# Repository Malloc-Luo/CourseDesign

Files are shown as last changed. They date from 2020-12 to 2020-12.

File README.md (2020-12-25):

## 简单温控系统

[Malloc-Luo/CourseDesign: 大三上微机原理课程设计 (github.com)](https://github.com/Malloc-Luo/CourseDesign)

### 一，创新

*   显示设定值和当前值—数码管
*   键盘设定温度
*   遥控控制温度
*   自制遥控器

### 二，技术层面

*   A/D转换
*   串口通信及传输协议设置
*   定时器中断
*   温度控制算法
*   ~~PID算法温度控制~~

### 三，设想

*   **设定温度**：键盘输入法；遥控法
*   **温度显示**：一个显示当前值，一个显示设定值，指示灯指示
*   **读取温度**：A/D转换
*   ~~**风扇与加热设备控制**：PID算法~~

### 四，任务分配

| 任务 | 人员 |
| --- | --- |
| 课程设计报告 | 马昊，常英剑 |
| 答辩PPT | 刘梦泽，李昱棋 |
| 遥控模块软件设计 | 刘梦泽，李昱棋 |
| 温控模块按键+数码管显示软件 | 马昊 |
| 温控模块AD转换温度获取 | 杨博然，常英剑，李昱棋 |
| 温控算法 | 李昱棋 |
| 通信协议设计及实现 | 李昱棋 |
| 电路原理图设计/绘制 | 李昱棋 |
| 遥控模块电路焊接 | 刘梦泽，杨博然 |

### 五，材料

[物品清单](https://docs.qq.com/sheet/DU2lkakxWcFdqTlZT?tab=BB08J2)

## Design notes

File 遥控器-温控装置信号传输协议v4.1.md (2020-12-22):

## 遥控器-温控装置信号传输协议v4.1

### 一、下位机与上位机串口通信协议：

上位机遥控器端蓝牙串口做为`master`，下位机蓝牙串口做`slaver`。串口参数：

*   波特率：9600
*   停止位：1
*   校验方式：无校验
*   帧长度：8 bit

每一帧数据有4 byte，分为 起始帧，指令帧，数据帧。

| Byte | Note |
| :--: | :---: |
|  1 | 0xA5 Frame Header |
|  2 | 指令帧 |
|  3 | 数据帧高8位 |
|  4 | 数据帧低8位 |

#### 数据位：

数据位为`%3.1f`类型的浮点数乘以10之后强制转换成`uint16_t`的数据，大小为0~999

#### 控制位：

控制位指示数据位的类型，占4bit

| Value | Note |
| --- | --- |
| 0x01  `SET_VAL` | 数据位为温度设定值 |
| 0x02  `ACTUL_VAL` | 数据位为温度当前值 |
| 0x04  ` RESET` | 重置温度最低值 |
| `Value` \| 0xf0 | 强制同步模式 |

#### 强制同步模式：

为了避免数据发生冲突而加入强制同步模式，下位机蓝牙模块由离线转为在线模式后的2400ms内为强制同步模式，此时下位机发送控制位的搞四位为`0xf`，在强制同步模式下：

*   温控模块、遥控模块的按键不可用
*   温控模块的不在串口中断中改变设定值、参考值、实际值
*   遥控模块解析指令时需要将接收到的指令按位与`0x0f`

### 二、程序实现示例：

合成发送数据帧：

```c
float tempf;
int16_t tempi= (int16_t)(tempf * 10);
uint8_t construction;

void bt_send_data(uint8_t *cmd, int16_t *dat)
{
    uint8_t * ptr = (uint8_t *)dat;
    /* 数据帧头0xa5 */
    uart_send(FRAME_HEADER);
    /* 指令帧 */
    uart_send(*cmd);
    /* 数据帧 */
    uart_send(*(ptr + 0));
    uart_send(*(ptr + 1));
}
```

还原接收数据帧：

```c
uint8_t instruct = Buffer[1];
int16_t temp = *(int16_t *)(Buffer + 2);
```

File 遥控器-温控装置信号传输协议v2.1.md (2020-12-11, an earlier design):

## 遥控器-温控装置信号传输协议v2.1

### 一、下位机与上位机串口通信协议：

上位机遥控器端蓝牙串口做为master，下位机蓝牙串口做slave。串口参数：

*   波特率：9600
*   停止位：1
*   校验方式：偶校验
*   帧长度：2 byte

其中一帧数据分为控制位和数据位，控制位占一帧数据的前4bit，数据位占一帧数据的后12bit。

#### 数据位：

数据位为`%3.1f`类型的浮点数乘以10之后强制转换成`uint16_t`的数据，大小为0~999

#### 控制位：

控制位指示数据位的类型，占4bit

| Value | Note |
| ----- | --- |
| 0x01  | 数据位为温度设定值 |
| 0x02  | 数据位为温度当前值 |
| 0x04  | 重置温度最低值 |

### 二、程序实现示例：

合成发送数据帧：

```c
float tempf;
uint16_t tempi = (int16_t)(tempf * 10);
uint8_t construction;

// 合成两个uint8_t数据
uint8_t Hbit = (uint8_t)(construction << 4 | tempi >> 8);
uint8_t Lbit = (uint8_t)(tempi & 0x00ff);
```

还原接收数据帧：

```c
uint16_t tempi = ((uint16_t)Hbit << 8 | (uint16_t)Lbit);
uint8_t construction = Hbit >> 4;
```

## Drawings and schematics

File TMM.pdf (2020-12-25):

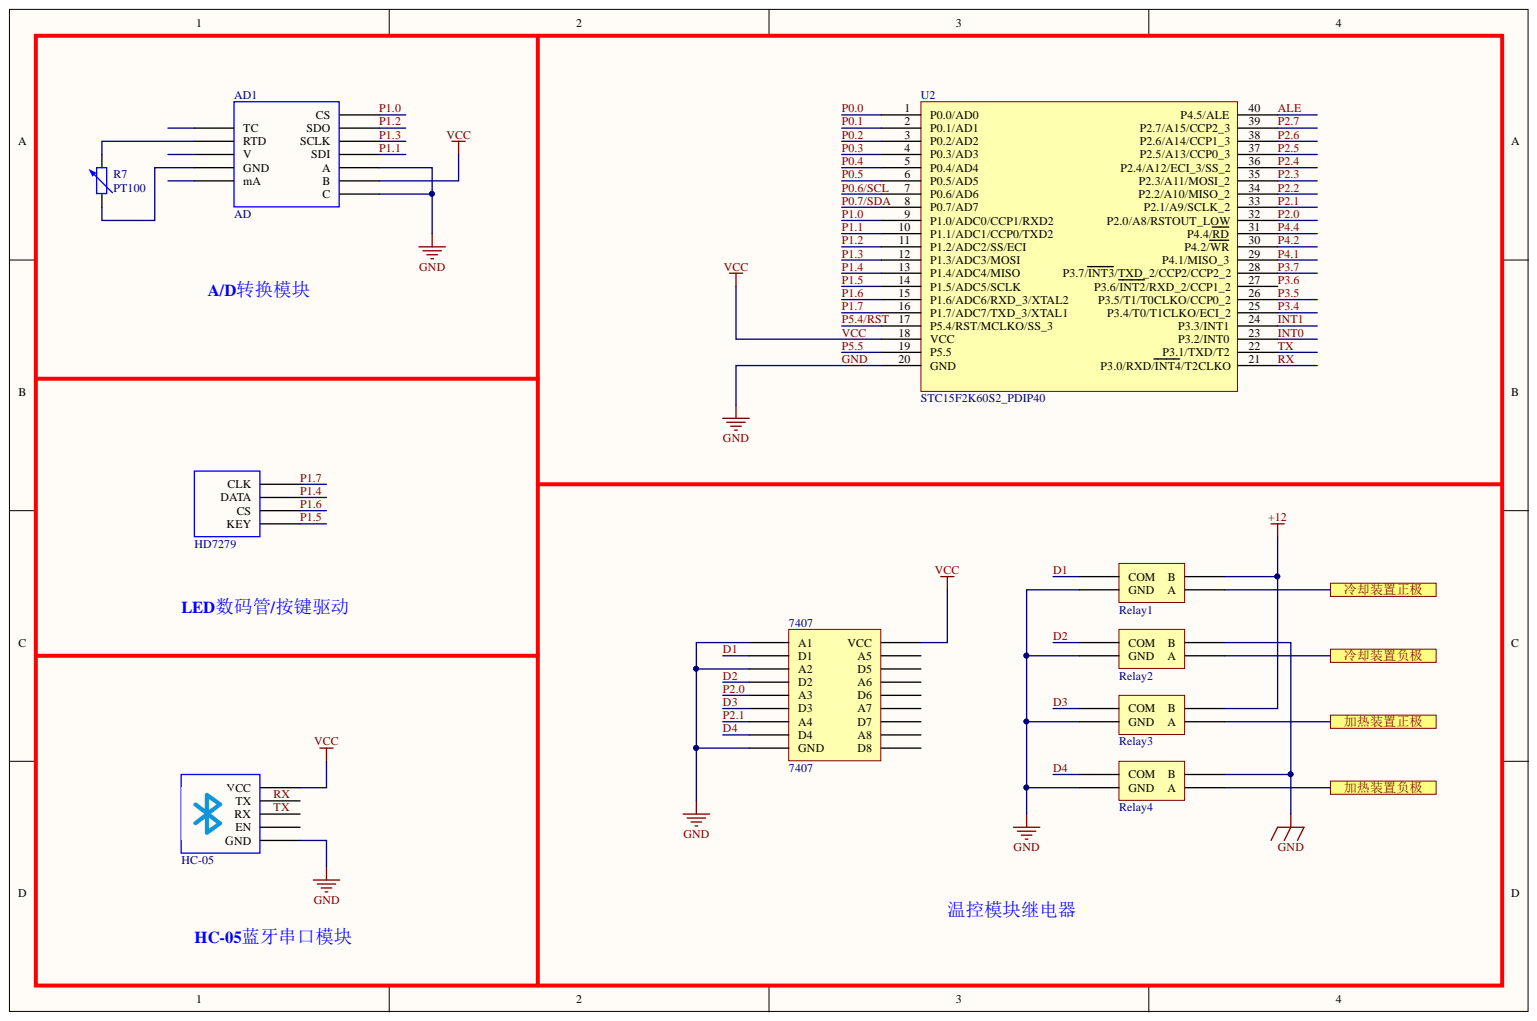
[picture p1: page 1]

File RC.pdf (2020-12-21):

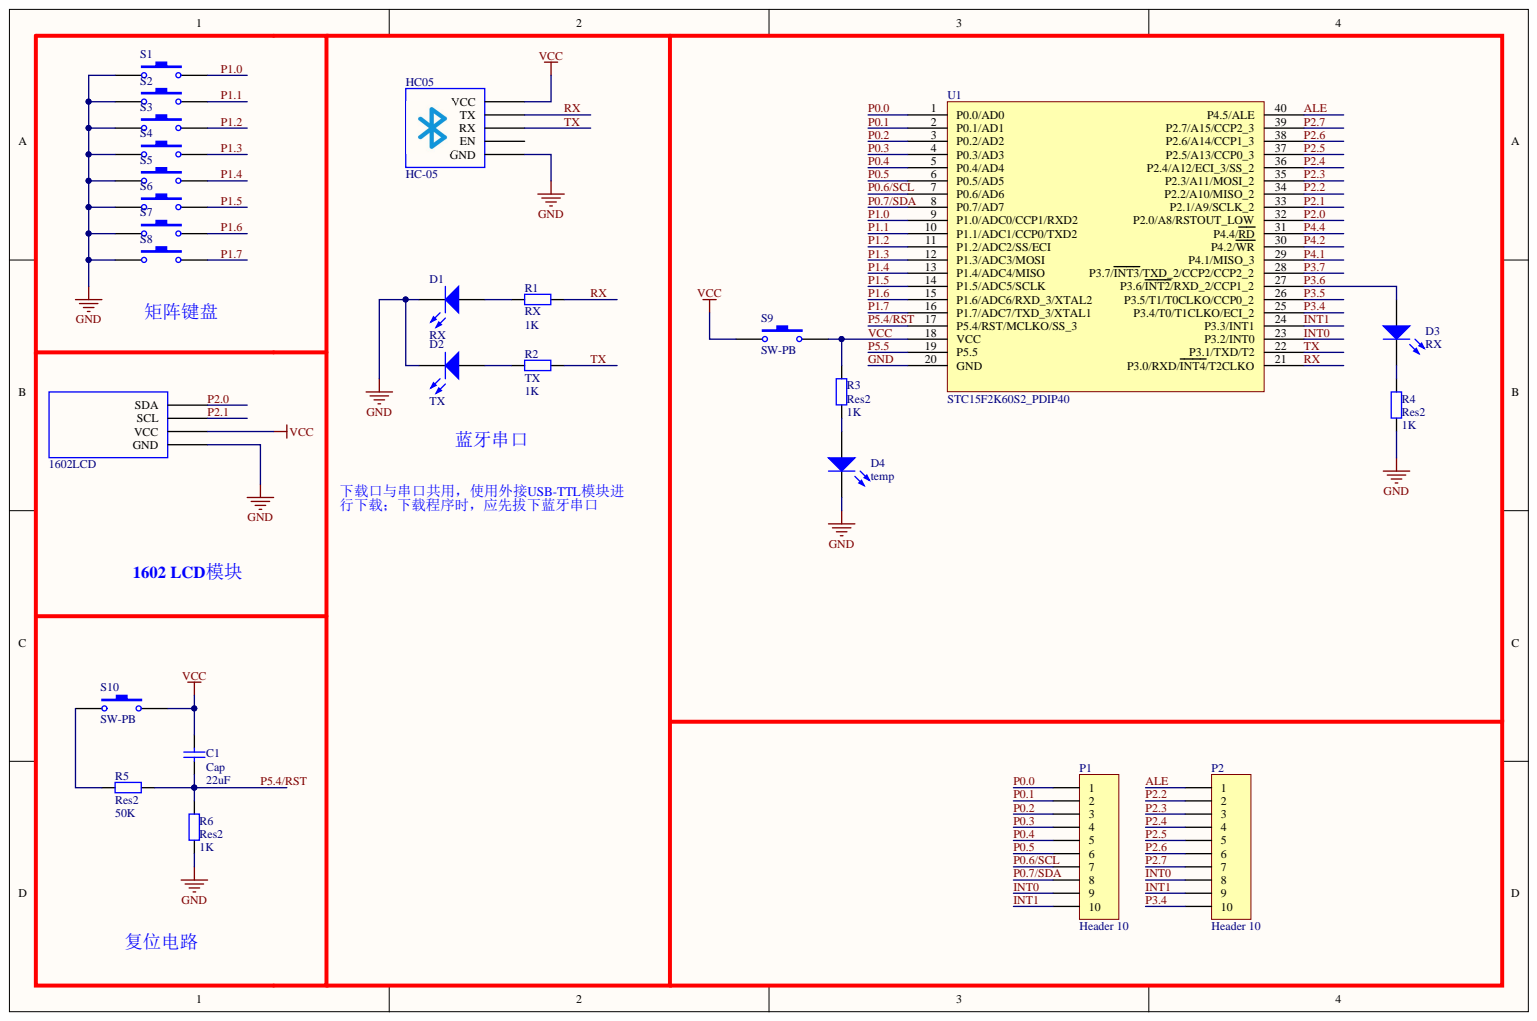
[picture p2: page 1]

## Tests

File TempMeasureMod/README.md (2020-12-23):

## 下位机硬件资源分配及软件架构

### 一、硬件资源分配

| I/O | 功能分配 |
| --- | --- |
| P2.0, P2.1 | 制冷制热设备控制 |
| P1.4, P1.5, P1.6, P1.7 | 数码管及键盘 |
| P1.0, P1.1, P1.2, P1.3 | AD转换接口 |
| P3.0, P3.1, T1(定时器) | 串口 |
| P3.6 | 状态指示LED |

### 二、软件架构及接口

```
src-->
    |--> main.c
    |--> bluetooth.c
    |--> schedul.c
    |--> LEDdisplay.c
    |--> ADtemp.c
inc-->
    |--> module.h
    |--> bluetooth.h
    |--> LEDdisplay.h
    |--> ADtemp.h
```

#### 1. 总体结构

所有程序通过一个基于T0的调度器进行带调度，T0初始化在主函数中，使能中断，中断周期50ms。全局变量：

```c
/* 系统时钟计数，50ms */
static uint16_t xdata systick = 0;
```

在定时器中断中计数并以此进行调度

```c
void timer0() interrupt 1 using 1
{
    systick++;
    /*系统调度*/
    system_scheduler();
}
```

所有模块的程序在调度任务中运行。调度任务一共有四个：

```c
// 10Hz频率，也就是100ms执行一次，其它同理
extern void Task_10Hz_1();
extern void Task_10Hz_2();
extern void Task_2Hz();
extern void Task_1Hz();
```

**注意！！不要在任务里使用超过50ms的延时函数**

函数定义在`schedul.c`中，只需要把你的程序接口放在上述四个函数中（有具体要求，不一定要你放，看下文）

所有的硬件初始化、工作寄存器初始配置都要放在`main.c`中`hardware_init()`函数中。

#### 2. 接口定义

每个模块的负责人员只需要实现一个接口就行了，具体怎么实现由自己负责，只要性能不拉跨就行！

`module.h`中放了使用到的全局变量，在测试模块时需要**包含此文件到你的测试工程**

```c
/**
 * 温控模块的温度
 * 将获取到的温度 * 10后转换成16位整形
 */
extern uint16_t ModTemperture;
/*
 * 设定的温度值
 */
extern uint16_t SetTemperture;
```

##### 1> A/D转换温度获取及加热制冷控制

功能实现放在`ADtemp.h`和`ADtemp.c`中，需要实现俩个功能：

*   温度获取
*   制冷制热设备控制接口

```c
/*
 * 获取当前温度值 0~999
 */
extern uint16_t get_actulval(void); 
/*
 * 制冷、制热，只要用户调用这个函数就能实现制冷和制热
 * state = 0 制冷
 * state = 1 制热
 */
extern void ctrl_device(uint8_t state);
```

##### 2> 数码管显示及按键处理

功能实现放在`LEDdisplay.h`与`LEDdisplay.c`中，需要实现的功能有：

*   显示设定值和当前值
*   处理和获取当前设定值

```c
/*
 * setval: 设定温度值
 * actulval: 实际温度值
 */
extern void LED_display(uint16_t setval, uint16_t actulval);
/*
 * 获取设定温度值
 */
extern uint16_t get_setval(void);
```

##### 3> 蓝牙串口

功能实现放在`bluetooth.h`和`bluetooth.c`中，需要实现的功能：

*   接收上位机蓝牙串口指令
*   向上位机蓝牙串口反馈数据

```c
void send_data(uint16_t temperture, uint8_t instruction);
void recv_data(uint16_t *, uint8_t *);
```

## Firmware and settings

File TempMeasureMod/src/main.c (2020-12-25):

/**********************FILE***************************
 * @filename: main.c
 * @author:   yuqi li
 * @data:     2020.12.11
 * @brief:    
 * 资源分配：
 * T1 ---> UART
 * P2.0, P2.1 制冷制热设备控制
 * P1.4, P1.5, P1.6, P1.7 数码管显示及键盘设置
 * P2, P0.4, P0.5 AD转换获取温度
 * P3.6接LED，若程序运行正常，则LED每隔1000ms闪烁一次
 *
 *****************************************************/
#include <reg51.h>
#include <math.h>
#include "bluetooth.h"
#include "LEDdisplay.h"
#include "ADtemp.h"
/* 系统时钟计数，20ms */
static volatile uint16_t data systick = 0;

int16_t ModTemperture = 0;
/* 默认为20°C */
int16_t SetTemperture = 200;
int16_t RefTemperture = 200;
uint8_t MasterCmd = ACTUL_VAL;
uint8_t RecvMasterCmd = 0;
bit initFlag = 1;

sfr AUXR = 0x8e;

/* 硬件初始化放在这里面 */
static void hardware_init()
{
    /*
     * 定时器0初始化，溢出周期20ms
     * 允许中断，且为高优先级
     */
    TMOD = 0x01;
    TH0  = 0xb1;
    TL0  = 0xe0;
    TCON = 0x11; 
    IE   = 0x83;
    IP   = 0x01;
    
    /*
     * 串口初始化，波特率9600，1停止位，偶校验
     */
    TMOD = 0x01 | 0x20;
    SCON = 0x50;
    AUXR = 0x00;
    TH1  = 0xfd;
    TL1  = 0xfd;
    IE   = 0x90 | 0x83;
    TR1  = 1;
    
    CS5550Init();
}


void main()
{
    /* 硬件初始化 */
    hardware_init();
    
    for (;;)
    {
        if (isUpdataVal)
        {
            isUpdataVal = 0;
            ModTemperture = get_actulval();
            LED_display(SetTemperture, ModTemperture);
        }
        if (taskFlag_10Hz)
        {
            Task_10Hz_1();
            taskFlag_10Hz = 0;
        }
        if (taskFlag_5Hz)
        {
            Task_5Hz();
            taskFlag_5Hz = 0;
        }
        if (taskFlag_2Hz)
        {
            Task_2Hz();
            taskFlag_2Hz = 0;
        }
    }
}

/**********************FUNCTION***********************
 * @brief: 系统调度器
 * @return: None
 * @note:  在此处调度
 *****************************************************/
void system_scheduler()
{
    /* 100ms执行一次 */
    if (systick % 5 == 0)
    {
        taskFlag_10Hz = 1;
    }
    
    if (systick % 5 == 1)
    {
        /* 100ms更新一次温度值 */
        isUpdataVal = 1;
    }
    
    /* 200ms执行一次 */
    if (systick % 10 == 3)
    {
        taskFlag_5Hz = 1;
    }
    
    /* 500ms执行一次 */
    if (systick % 25 == 2)
    {
        taskFlag_2Hz = 1;
    }
}


void timer0() interrupt 1 using 1
{
    TH0  = 0xb1;
    TL0  = 0xe0;
    
    systick++;
    /*系统调度*/
    system_scheduler();
}

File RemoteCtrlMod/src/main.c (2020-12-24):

/**********************FILE***************************
 * @filename: main.c
 * @author:   yuqi li
 * @data:     2020.12.11
 * @brief:
 * 资源分配：
 * T1 ---> UART
 *
 *****************************************************/
#include <reg51.h>
#include "bluetooth.h"
#include "LCDdisplay.h"
/* 系统时钟计数，50ms */
static volatile uint16_t data systick = 0;

int16_t ModTemperture = 0;
int16_t SetTemperture = 0;
int16_t RefTemperture = 0;
uint8_t SlaveCmd = SET_VAL;

sfr AUXR = 0x8e;

/* 硬件初始化放在这里面 */
static void hardware_init()
{
    /*
     * 定时器0初始化，溢出周期20ms
     * 允许中断，且为高优先级
     */
    TMOD = 0x01;
    TH0  = 0xb1;
    TL0  = 0xe0;
    TCON = 0x11;
    IE   = 0x83;
    IP   = 0x01;

    /*
     * 串口初始化，波特率9600，1停止位，偶校验
     */
    TMOD = 0x01 | 0x20;
    SCON = 0x50;
    AUXR = 0x00;
    TH1  = 0xfd;
    TL1  = 0xfd;
    IE   = 0x90 | 0x83;
    TR1  = 1;

    Init_Lcd();
}


void main()
{
    /* 硬件初始化 */
    hardware_init();

    for (;;)
    {
        signal_display();

        if(isReset) //如果按下重置参考值键，展示重置成功
        {
            display_reset();
            isReset = 0;
        }
        else
            LCD_display(SetTemperture, ModTemperture);

        if(isShowRef | isBelow)//按下展示参考范围键（S2）或者当设定温度超出设定范围时，展示设定温度范围
        {
            display_reftemp(RefTemperture);
            isShowRef = 0;
            isBelow = 0;
        }
    }
}

/**********************FUNCTION***********************
 * @brief: 系统调度器
 * @return: None
 * @note:  在此处调度
 *****************************************************/
static void system_scheduler()
{
    /* 100ms执行一次 */
    if (systick % 5 == 0)
    {
        Task_10Hz_1();
    }

    if (systick % 10 == 1)
    {
        Task_5Hz();
    }

    /* 500ms执行一次 */
    if (systick % 25 == 2)
    {
        Task_2Hz();
    }
}

void timer0() interrupt 1 using 1
{
    TH0  = 0xb1;
    TL0  = 0xe0;

    systick++;
    /*系统调度*/
    system_scheduler();
}

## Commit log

2020-12-11 ✨[1.1] [add] 添加通信协议v2.0
2020-12-11 🔧[1.2] [fix] 修改蓝牙串口通信协议
2020-12-11 ✨[2.0] [add] 添加下位机代码框架
2020-12-11 📢[2.1] [change] 修改readme
2020-12-12 📢[2.2] [change] 下位机代码框架更新
    更改了一些接口
2020-12-12 ✨[2.3] [add] 上位机代码框架
2020-12-13 🔧[2.4] [fix] 修改蓝牙串口通信协议(v3.0)
2020-12-13 ✨[2.5] [add] 下位机串口通信部分完成--未测试
2020-12-13 🔧[2.6] [fix] 改变下位机IO资源分配
    之前考虑不周，下位机P0做IO时要接上拉电阻，然而实验板天然受限~
2020-12-14 🔧[2.7] [fix] 改变定时器周期为20ms
    0.
    1. 修改定时器计数初值的bug
    2. 添加RC离线检测
    3. 添加LED状态指示
    [bluetooth.c, main.c]
2020-12-14 LCD列显示、显示℃
2020-12-14 LCD列显示（12.15）
2020-12-15 📢[2.8] [change] 修改编码格式为utf-8
    1. 修改编码格式为utf-8
    2. 更改定时器周期为20ms
    3. 加入蓝牙离线检测和LED状态指示
2020-12-15 遥控按键操作+重置成功显示
2020-12-16 🔧[2.9] [fix] 蓝牙通信4.0
2020-12-16 ✨[2.10] [add] 蓝牙数据传送完成
    1. 巨坑！不要用移位，好像有硬件问题，坑死我了！草
    [bluetooth.c, main.c]
2020-12-16 [2.11] [change] 代码格式化，蓝牙接收配置
2020-12-16 展示设定温度参考范围
2020-12-16 展示设定温度参考范围（添加部分注释）
2020-12-16 🔧[2.13] [fix] 修复蓝牙接收问题
2020-12-17 📢[2.14] [change] 修改下位机代码框架编码为utf-8
2020-12-17 📢[2.15] [change] 进行了一些非必要优化
2020-12-18 📢[2.16] [change] 非必要优化
2020-12-18 🔧[2.17] [fix] 温度值改为signed int，考虑负值
    [bluetooth.c, main.c]
2020-12-18 ✨[2.18] [add] 下位机框架更新，部分优化，蓝牙接收
    1. 添加蓝牙通信部分代码（未测试）
    2. 温度值使用signed int，可以为负值，解决溢出问题
    3. 部分代码优化，减小代码体积
    [bluetooth.c, main.c]
2020-12-18 实现温度负值展示
2020-12-19 扩展温度范围
2020-12-21 ✨[2.20] [add] 下位机数码管部分，上位机原理图
2020-12-21 💡[3.0] [merge] 合并测试，可以显示数据及通信
    bug1: 数码管异常闪烁
    bug2: 通信数据同步问题
    [main.c]
2020-12-22 🔧[3.1] [fix] 数据同步问题修复（to be tested）
    基本思路是加入一个强制同步模式，在蓝牙刚上线的时候温控模块强行将数据同步到遥控模块，在此期间温控、遥控模块的按键都不能使用；同时温控模块不会从蓝牙串口更新数据。整个过程持续2.4 s
    [bluetooth.c]
2020-12-22 🔧[3.2] [fix] 修复了蓝牙离线检测部分，及强制同步模式
    bug: 同步还是会出问题
    [bluetooth.c, main.c]
2020-12-23 显示蓝牙连接状况
2020-12-23 改善显示蓝牙连接状况
2020-12-23 🔧[3.3] [fix] 修复数码管闪烁问题，修复数据同步问题
    数码管每次显示之前先重置就能解决闪烁问题，或者可以改成每隔一段时间重置
    [bluetooth.c, main.c]
2020-12-24 🔧[3.5] [fix] 迁移到STC15F2K60S2上；修复遥控模块LCD乱码问题
    1. 在STC15F2K60S2平台上跑，纪念第一次设计电路板！
    2. 修复LCD蓝牙乱码，改了延时就好了
    3. 奥里给！
    [main.c]
2020-12-25 🔧[3.6] [fix] 初始温度设定为20°C；文件编码换成utf-8
2020-12-25 🔧[3.7] [fix] 设定值数据检查；最大值改为100
    bug1: 最小值不知道为啥没用了
    [bluetooth.c]
2020-12-25 ✨[4.0] [add] 完善原理图
    [rc.SchDoc, tm.SchDoc]
2020-12-25 🔧[4.1] [fix] pdf版的原理图放错了😅
